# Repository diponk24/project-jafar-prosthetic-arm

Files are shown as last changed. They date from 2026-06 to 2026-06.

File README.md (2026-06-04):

# Project Jafar – Prosthetic Arm

## Overview

Project Jafar is a prosthetic arm prototype designed to explore assistive robotics through EMG-based muscle signal control and voice-command operation.

The arm incorporates a differential mechanism for finger movement, a foldable elbow joint, and rotational elbow motion to replicate essential arm functionalities.

---

## Features

- EMG sensor-based control
- Voice-command operation
- Differential finger actuation mechanism
- Finger folding functionality
- Foldable elbow joint
- Rotatable elbow movement
- Modular design for future upgrades

---

## Working

The prosthetic arm can be controlled using:

1. **EMG Sensors**
   - Detect muscle activity from the user.
   - Convert signals into movement commands.

2. **Voice Commands**
   - Execute predefined actions through voice input.

The system performs:
- Finger folding
- Gripping actions
- Elbow folding
- Elbow rotation

---

## Components Used

- Arduino / ESP32
- EMG Sensors
- Servo Motors
- Voice Recognition Module
- Mechanical Differential Mechanism
- Power Supply

---

## Technologies

- Embedded Systems
- Robotics
- Sensor Integration
- Mechanical Design

---

## Future Scope

- Individual finger control
- Improved grip strength
- Wireless connectivity
- Mobile application integration
- Advanced gesture recognition

---

## Team

Project Jafar was developed by a team of 7 members as an assistive robotics and prosthetic arm prototype focused on affordable and practical functionality.

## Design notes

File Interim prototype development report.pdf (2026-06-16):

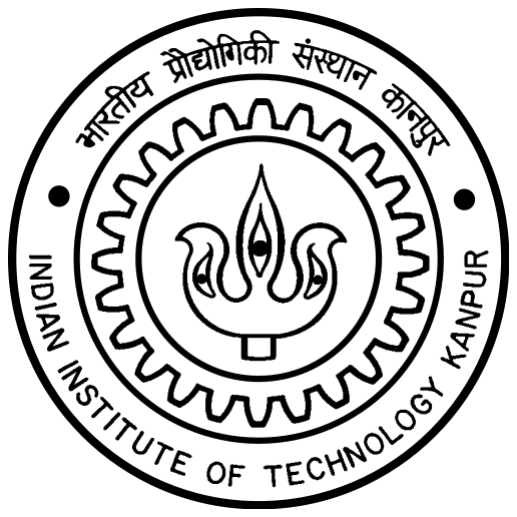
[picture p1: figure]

### Indian Institute of Technology Kanpur

## Department of Mechanical Engineering

# Project Jafar

# Design and Development of a 3D-Printed Differential-Actuated Prosthetic Arm

# Course: ME252 — Theory of Mechanisms and Machines

### Project Team

Anandan Iyer | anandani24@iitk.ac.in | Prakhar | prakhark24@iitk.ac.in
Ayush Dwivedi | ayushd24@iitk.ac.in | Sarthak Patel | sarthakp24@iitk.ac.in
Dipon Konar | diponk24@iitk.ac.in | Shubham | shubham24@iitk.ac.in
Lakshya Gupta | lakshyag24@iitk.ac.in

## June 16, 2026

# Contents

1 Overview | 1
2 Iteration 1: Proof-of-Concept Prototype | 1
3 Iteration 2: Differential-Actuated Multi-DOF System | 1
4 Results and Conclusion | 4
5 Future Scope | 4
References | 5
A Appendix | 5

# 1 Overview

Project Jafar is a noble effort to design and develop a prosthetic arm within an affordable price range for an 8 year old kid named Jafar who doesn’t have the ability to use either of his arms. The first iteration involved fabricating a singe-DOF proof-of-concept which incorporated finger-actuation and the ability to grip fragile objects. In the second iteration, we worked on developing athree-DOF platform incorporating finger actuation and, elbow flexo-extension driven by a differential actuation mechanism and controlled wirelessly via an ESP32 microprocessor.

Parameter | Iteration 1 | Iteration 2
DOF | 1 (Finger actuation) | 3 (Finger, Elbow, Prono)
Actuation | Direct string, single motor | Differential mechanism
Microcontroller | Arduino Nano | ESP32
Input modality | EMG sensor | Bluetooth & Wi-Fi voice
Tendon routing | Ad-hoc, unguided | Guided channels + hooks
Table 1: High-level comparison across design iterations.

# 2 Iteration 1: Proof-of-Concept Prototype

## 2.1 Mechanical Design

Iteration 1 employed asingle motor which drives fingers simultaneously through a combined string tendon arrangement: individual finger strings were merged upstream and connected to a single motor. Although the mechanism was quick to implement, it was prone to multiple failures.
- No force distribution: equal motor tension was applied uniformly to all tendons regardless of per-finger contact resistance or object interaction which resulted in disproportionate actuation and instability.
- Inconsistent string tension: unguided routing introduced variable friction, slack, and path-dependent losses, which lead to unpredictable grip profiles.
- Recurring string failures: uncontrolled routing concentrated stress at sharp bends, contact edges, and termination points, accelerating wear and leading to frequent tendon breakage under cyclic loading.
- Rigid inter-finger coupling: all fingers were mechanically linked which prevented them from moving independently that highlighted another design flaw. The elbow joint was kept passive for this prototype, which housed the 7.4V battery, which was used to drive the motor.

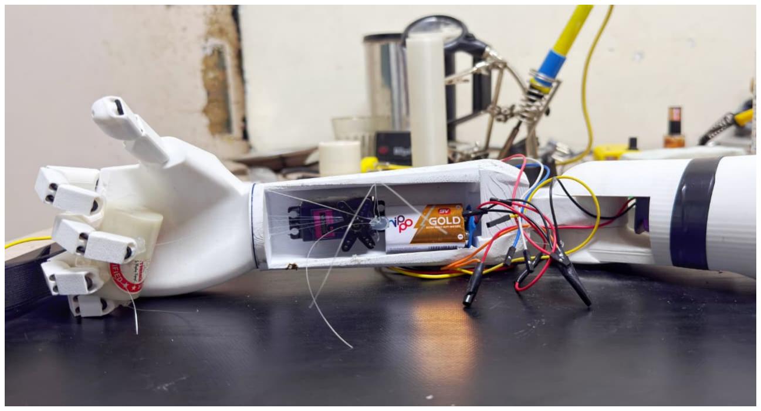
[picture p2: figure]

Figure 1: Iteration I prototype: signle-DOF combined-string finger actuation

## 2.2 Control System

The control architecture used an Arduino Nano to sample the analogue voltage from a surface EMG sensor band. Myoelectric potentials were kept as threshold to generate binary motor on/off commands. Reliable electrode placement was another hurdle; we were seldom able to position EMG bands correctly, which led to difficulties in interpreting the signal. Attempts were made to set the motor’s position based on the signal strength received, but the attempts failed because the signal was not stable enough, this led to the limitation to keep fingers either fully open or closed, and not in any intermediate state.
These issues collectively led to the full architectural redesign leading to Iteration 2.

# 3 Iteration 2: Differential-Actuated Multi-DOF System

## 3.1 Redesign Rationale

The transition to Iteration 2 was driven by a few principal deficiencies, along with a shift in the control strategy from the EMG-based sensing used in the first iteration to a more reliable and implementable approach: (i) Structural inconsistencies in the CAD model with no defined tendon pathways or dedicated electronics accommodation. (ii) Recurring string failures from uncontrolled stress concentrations. (iii) Unreliable finger control from a coupled tendon architecture. (iv) The single-DOF constraint precluding the three-DOF mobility required for functional prosthetic use.

## 3.2 Three-DOF Mechanical Architecture

The upgraded system implements three independently motorised degrees of freedom. DOF 1 provides finger actuation via the differential mechanism (Section 3.3). DOF 2 delivers elbow flexo-extension through a direct-drive scheme in which the motor housing is fixed to the upper-arm segment and the output shaft is rigidly coupled to the forearm, producing pure joint rotation without additional transmission elements. DOF 3 enables forearm pronosupination via a motor whose axis is co-axial with the forearm’s longitudinal centre-line. All three motors are independently addressable through dedicated PWM channels on the ESP32.

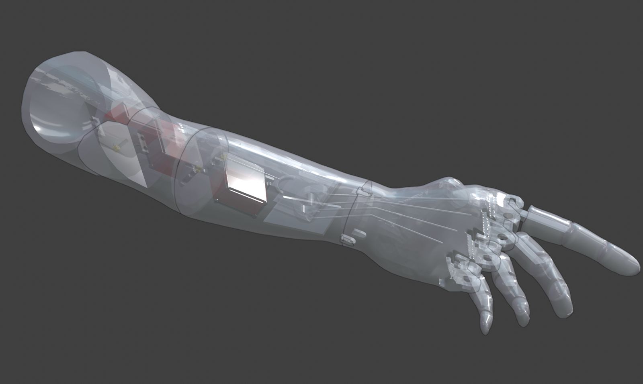
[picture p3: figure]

Figure 2: Iteration 2 three-DOF kinematic layout: motor placement and joint axes.

## 3.3 Differential Finger Actuation

### 3.3.1 Objective

As established in Section 2.1 (Mechanical Design), the initial finger actuation required a more robust system for force distribution, hence we will be implementing a differential mechanism for this part of the prosthetic. The differential mechanism enabled a balanced and adaptive force distribution among the fingers, allowing actuation to adjust based on resistance at each finger. If one of the fingers faces resistance when gripping a particular object, the rest of the the fingers continue to grip around the object, and when all the fingers curl, further tension in the strings start to grip the object tighter. This resulted in a smoother motion and improved grasping performance, especially when contact conditions vary across fingers.

### 3.3.2 Working principle

Based on the kinematic constraints of strings, the displacement of the primary pulley P3 ( is distributed through the differential tree according to the following relations:

D5 + D6 = 2D7

D1 + D2 = 2D5

D3 + D4 = 2D6

When one of the fingers start feeling resistance, say finger 1 for example, it would stop moving, and rest of the motion would go instead to its coupled finger, in this case finger 2 (D1 = 0 and D2 = 2D5). In case both the coupled fingers feel resistance, then the motion would instead go to the other coupled pulley. (In this case for example, P1 stops moving and P2 take all the motion). The physical definition of each variable is illustrated in Figure 3:

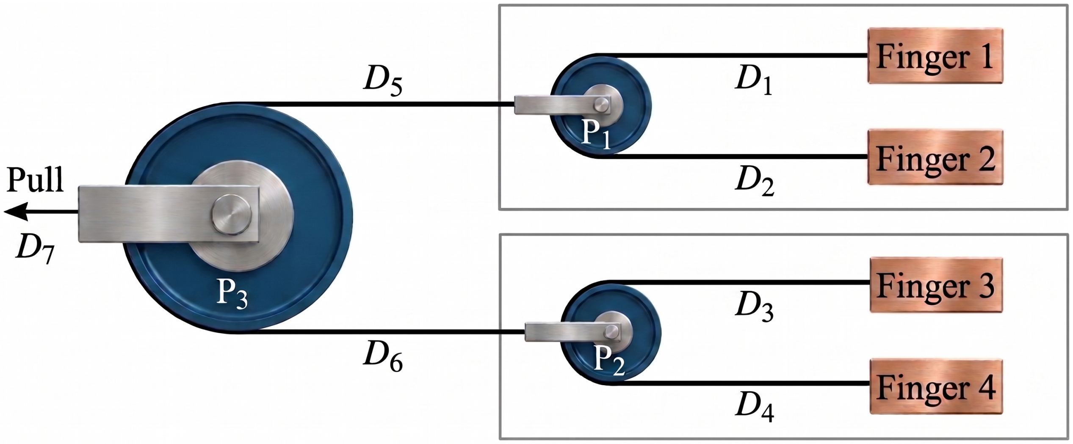
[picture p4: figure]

Figure 3: Simplified view of a differential mechanism

### 3.3.3 Implementation

In our implementation of the differential mechanism, given space constraints, we had to move away from the basic pulley-based Atwood machine shown in Figure 3. Our approach combined the pulleys P1, P2, and P3 into one single mechanism. The heart of the mechanism is shown in blue atop the pink slide, which slides comfortably into the red slot (as seen in Figure 4). In the front part, which opens towards the fingers (which functionally acts like P1 and P2 and are similar to traditional pulleys), there are holes for strings to enter, with a toroidal cavity for each pair of fingers. The string can move freely (after using a suitable lubricant, so the string does not wear out). To implement the P3, the Blue part uses the red part as a hinge to rotate. When there is unequal motion between pulleys P1 and P2, the blue part rotates about the red part; thus, if required and one of the pulleys stalls due to resistance, the mechanism can continue sliding, on the tracks, with the blue part rotating to accomodate the movement.

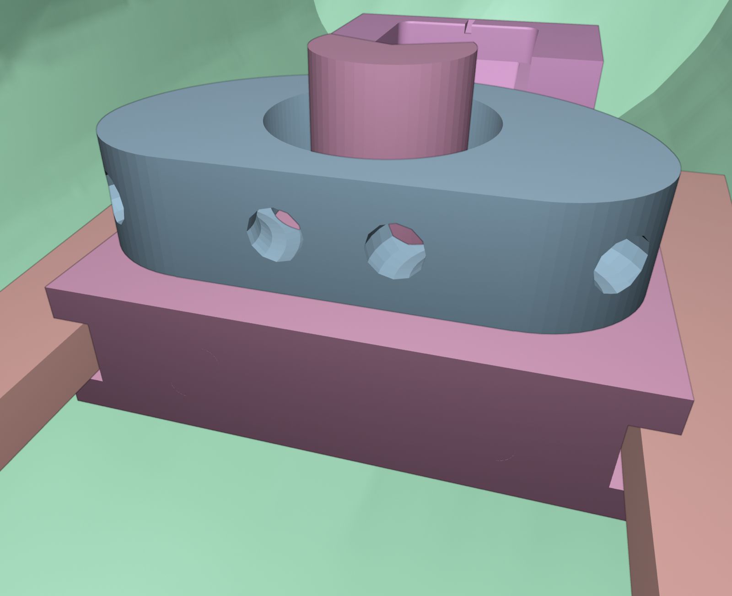
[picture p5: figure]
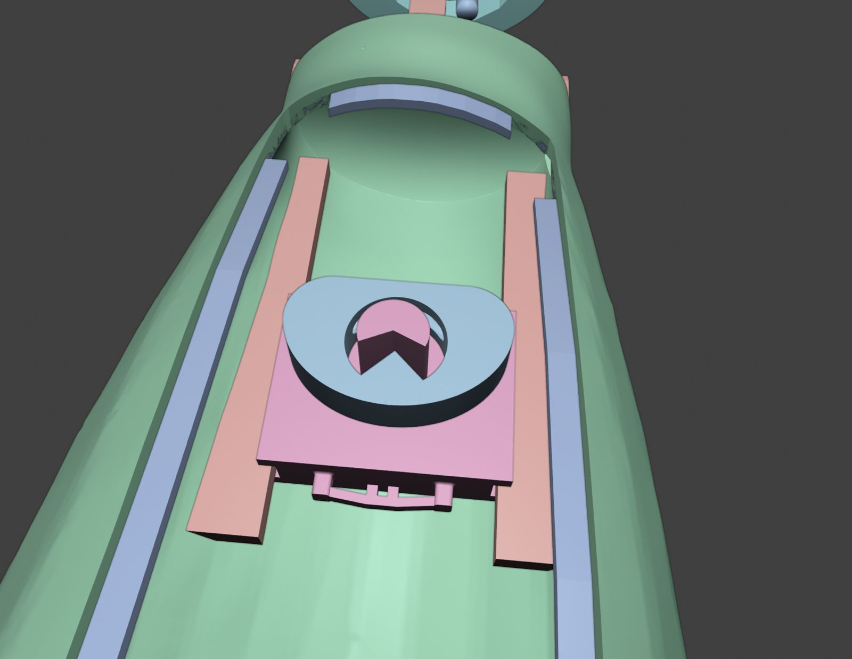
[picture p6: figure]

(a) Bird’s-eye view. | (b) Close-up view.
Figure 4: Views of the differential mechanism assembly.
Property | Iteration 1 - Prototyping | Iteration 2 - Differential
Force distribution | Equal, load-independent | Adaptive per-finger
Grasp adaptability | None (rigid coupling) | Passive compliance
Tendon routing | Unguided, ad-hoc | Guided channels + hooks
Frictional losses | High (uncontrolled contacts) | Reduced (smooth guided paths with lubrication)

Table 2: Actuation mechanism comparison across iterations.

## 3.4 CAD Redesign

The updated design adopts a more structured and integrated approach to improve overall system performance. The forearm geometry was redesigned to enable functioning of both the actuation system and electronics within a dedicated internal cavity which significantly improves the spatial organization, component protection, and the ease of assembly. Carefully planned provisions for servo placement and wire routing have been useful in reducing clutter, minimized interference between components, and enhanced long-term maintainability and serviceability. The forearm was also modified to better integrate the differential mechanism which resulted in more efficient force transmission and smoother, more coordinated motion during operation. In addition, the upper arm was redesigned to incorporate an extra degree of freedom at the elbow joint(passive in the initial iteration), which increases the overall range of motion of the system. Further improvements were made to the palm and finger assemblies. Guided string channels were built directly into the CAD model, replacing the earlier ad-hoc routing approach to ensure a cleaner and more reliable tendon path. Intermediate hooks and supports were added along the tendon path to maintain proper alignment to reduce slack and minimize frictional losses during the motion. These changes ensure a more consistent tension distribution and smoother, more precise actuation across all fingers.

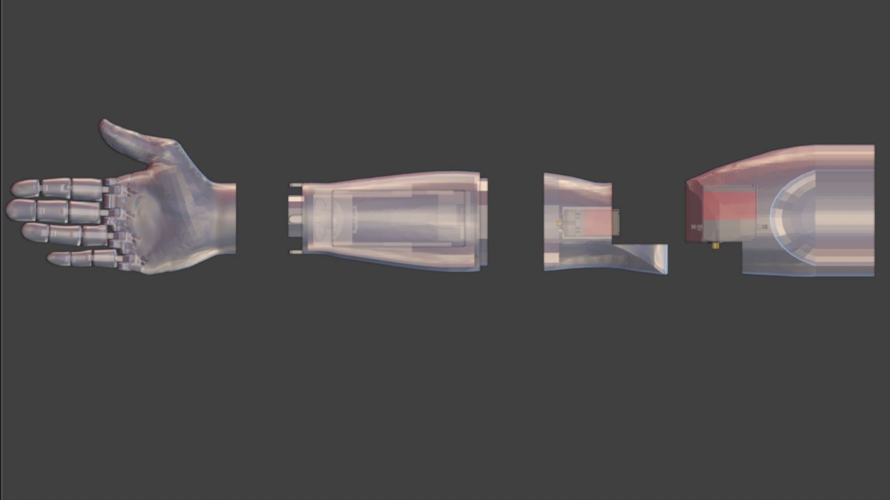
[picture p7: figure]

(a) Iteration 1: unstructured interior

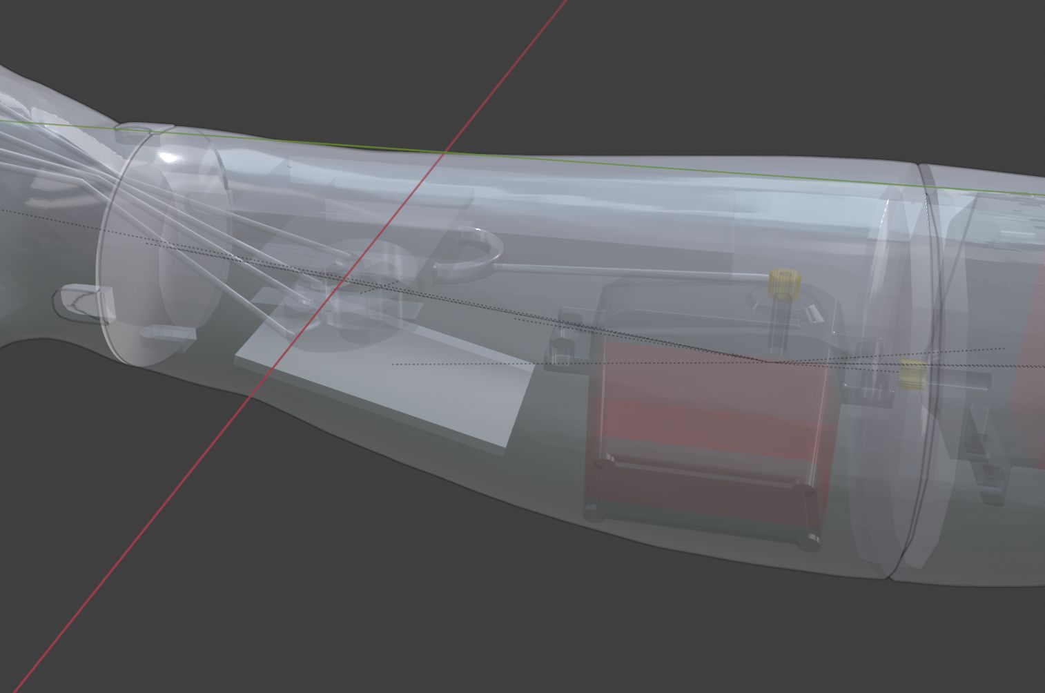
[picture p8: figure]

(b) Iteration 2: CAD with integrated cavity, servo mounts, and wire channels

## 3.5 Electronics and Control System

### 3.5.1 Control Architecture

The control system is built around the ESP32 microcontroller, selected for its integrated Bluetooth and Wi-Fi capabilities. This enables multiple wireless input methodologies on a single hardware platform while providing sufficient PWM-capable GPIO pins for independent control of the finger and elbow actuation motors.
To ensure stable operation, the motor supply and logic supply are regulated independently. This minimizes switching transients generated by the motors, thereby improving system reliability and preventing voltage fluctuations from affecting control performance.

### 3.5.2 Wireless Control Methodologies

During development, we tried out two wireless approaches. This revealed a clear trade-off: one was much simpler to implement, but the other gave the system far more autonomy.

Bluetooth Serial Interface

In the initial approach, the ESP32 was configured as a Bluetooth device and paired with a mobile phone. Commands were transmitted using a Bluetooth Serial Terminal application, with Google Assistant acting as a voice-to-text front-end.
The spoken command was converted to text via cloud-based processing and relayed to the ESP32, where it was parsed against predefined command tokens. While straightforward to implement, this method suffered from internet dependency, increased latency, and reduced reliability under wireless interference.

Wi-Fi Offline Voice Interface

To overcome these limitations, a Wi-Fi-based offline voice interface was implemented. A Python script running on a laptop connected to the ESP32 over a local Wi-Fi network utilizes a pretrained offline speech recognition library (Vosk) to detect predefined command phrases. Recognized commands are transmitted to the ESP32 via HTTP requests, enabling real-time actuation without reliance on internet connectivity. The command structure was designed for clarity and robustness. Finger actuation (DOF 1) is controlled using discrete commands, while higher degrees of freedom corresponding to elbow and rotational motion (DOF 2 and DOF 3) follow a structured format. The actuation angles are limited to fixed values such as 0°, 30°, 60°, and 90° for easier control and can be further increased. This separation simplifies parsing and improves recognition reliability.

Voice Command | DOF Target | Motor Action
grip | DOF 1 (Fingers) | Close fingers via differential actuation
loose | DOF 1 (Fingers) | Open fingers (release motion)
motor N turn θ | DOF 2 / DOF 3 | ◦ Rotate motor N to θ
Table 3: Voice command vocabulary and corresponding motor actions.

The Wi-Fi-based interface provides a more reliable and low-latency control solution compared to the Bluetooth approach, making it better suited

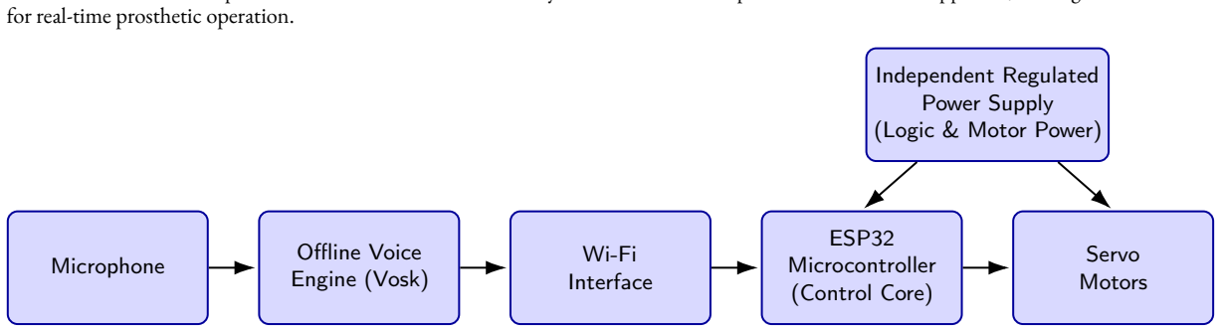
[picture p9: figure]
for real-time prosthetic operation.; Microphone; Offline Voice; Engine (Vosk); Wi-Fi Interface; ESP32 Microcontroller (Control Core); Servo Motors; Independent Regulated Power Supply (Logic & Motor Power)

Figure 5: System control architecture and offline voice communication flow.

# 4 Results and Conclusion

The project progressed through two iterations, each improving upon the limitations of the previous design.
Iteration 1 resulted in a fabricated and tested, successfully demonstrating basic finger actuation. However, issues such as inconsistent tension and unreliable control highlighted the need for redesign.
In Iteration 2, we focused on improving different parts of the system separately. The updated CAD design made the structure more organized and helped in proper routing of the strings. The differential mechanism showed better force distribution and smoother finger movement during testing. On the electronics side, the ESP32 control system and the Wi-Fi based voice interface were tested independently and worked reliably with low delay.
At this stage, all the major subsystems have been developed and tested individually. The next step is to integrate everything together and test the full system with all degrees of freedom working simultaneously. Overall, the second iteration provides a much more stable and improved base compared to the first prototype.

# 5 Future Scope

The next step is to integrate all the subsystems and test the complete prosthetic arm. This includes running all three degrees of freedom together and checking performance during actual grasping tasks. The control system can be improved by bringing back EMG-based input or using physical buttons along with voice commands for more intuitive use. Adding feedback systems, such as force or position sensing, can help improve accuracy and control. On the mechanical side, further refinement of the differential mechanism and string routing can reduce friction and improve durability. Reducing weight and making the design more compact will also improve usability. The command input can be expanded to allow smoother and more precise movements instead of only fixed angle steps. Overall, the current design provides a good base for developing a more reliable and user-friendly prosthetic arm.

# References

V. Khatik and A. Saxena, “A Novel Slack Tolerant, Sliding Pulley Differential Mechanism for Adaptive Grasping,” Proc. ASME IDETC-CIE, 47th Mechanisms and Robotics Conf., Vol. 8, p. V008T08A071, Aug. 2023. doi: 10.1115/DETC2023-115115.

Viral Science Creativity, “Arduino Flex Sensor Controlled Robot Hand,” Sep. 18, 2022. Available: https://www.viralsciencecreativity.com/post
/arduino-flex-sensor-controlled-robot-hand.

Enabling the Future, “Upper Limb Prosthetics,” Available: https://enablingthefuture.org/upper-limb-prosthetics/

Kwawu Arm Project, “Kwawu Arm 3.0 Wrap Version,” Available: https://www.printables.com/model/653545-kwawu-arm-30-wrap-version

# A Appendix

## A.1 Python Voice Recognition Script

import sounddevice as sd
import json
from vosk import Model , KaldiRecognizer import requests

model = Model (" model ")

rec = KaldiRecognizer (
model , 16000 ,
’[" grip " ," loose " ," motor one " ," motor two " ," turn " ," zero " ," thirty " ," sixty " ," ninety "] ’

)

ESP_IP = " 192.168.4.1 "

motor_map = {
"one ": 1 ,
"two ": 2

}

angle_map = {
" zero ": 0,
" thirty ": 30 ,
" sixty ": 60 ,
" ninety ": 90

}

def send ( cmd , motor = None , angle = None ) : try :
if cmd in [" grip ", " loose "]:
url = f" http ://{ ESP_IP }/ cmd ? mode ={ cmd }"
else :
url = f" http ://{ ESP_IP }/ cmd ? mode = move & motor ={ motor }& angle ={ angle }"

requests . get ( url )
print (" Sent :", url )

except :
print (" ESP not connected ")

def process ( text ):
print (" Heard :", text )

if " grip " in text :
send (" grip ")
return

if " loose " in text :
send (" loose ")
return

motor = None

53 | angle = None

54
55 | for word in motor_map :
56 | if word in text :
57 | motor = motor_map [ word ]

58
59 | for key in angle_map :
60 | if key in text :
61 | angle = angle_map [ key ]

62
63 | if motor and angle is not None :
64 | send (" move ", motor , angle )

65
66 | def callback ( indata , frames , time , status ):
67 | if rec . AcceptWaveform ( bytes ( indata )) :
68 | result = json . loads ( rec . Result () )
69 | text = result . get (" text ", "")

70
71 | if text :
72 | process ( text )

73
74 print (" Speak now ... ")

75
76 | with sd . RawInputStream ( samplerate =16000 ,
77 | blocksize =8000 ,
78 | dtype =’int16 ’,
79 | channels =1 ,
80 | callback = callback ) :
81 | while True :
82 | pass

## A.2 ESP32 Control Code

1
2 | # include < WiFi .h >
3 | # include < WebServer .h >
4 | # include < ESP32Servo .h >

5
6 WebServer server (80) ;

7
8 | Servo finger ; | // DOF 1
9 | Servo elbow1 ; | // DOF 2
10 | Servo elbow2 ; | // DOF 3

11
12 | void handleCmd () {
13 | String mode = server . arg (" mode ");

14
15 | if ( mode == " grip ") {
16 | finger . write (90) ; | // close
17 | }

18
19 | else if ( mode == " loose ") {
20 | finger . write (0) ; | // open
21 | }

22
23 | else if ( mode == " move ") {
24 | int motor = server . arg (" motor "). toInt () ;
25 | int angle = server . arg (" angle ") . toInt () ;

26
27 | if ( motor == 1) elbow1 . write ( angle ) ;
28 | if ( motor == 2) elbow2 . write ( angle ) ;
29 | }

30
31 | server . send (200 , " text / plain ", "OK");
32 | }

33
34 void setup () {

35 | WiFi . softAP (" ESP32_ARM ", " 12345678 ");

36
37 | finger . attach (13) ;
38 | elbow1 . attach (12) ;
39 | elbow2 . attach (14) ;

40
41 | server . on ("/cmd ", handleCmd );
42 | server . begin () ;
43 | }

44
45 | void loop () {
46 | server . handleClient () ;
47 | }

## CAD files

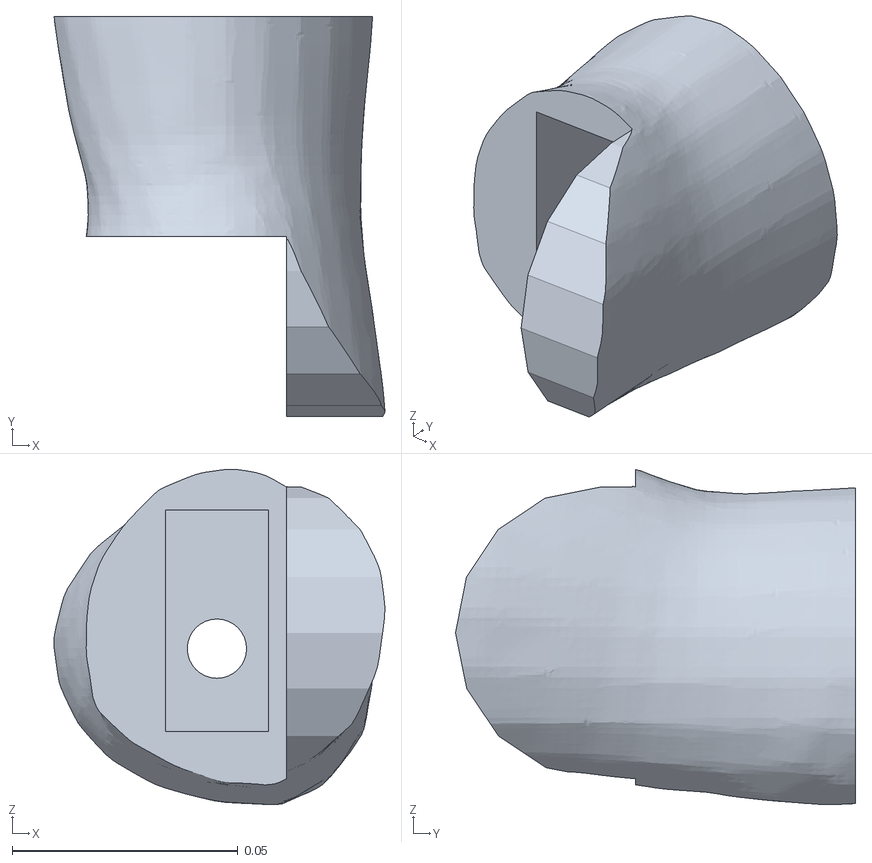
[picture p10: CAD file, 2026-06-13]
JAFAR CAD post modification/Fingers/Arm/elbow.stl
0.0733 x 0.0886 x 0.0743

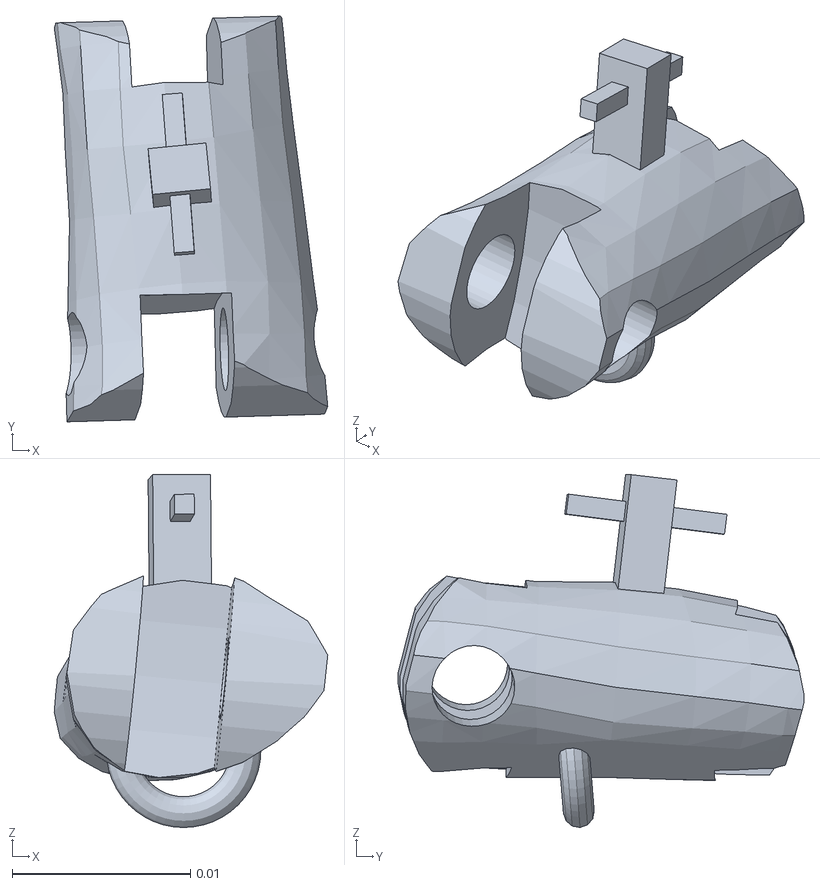
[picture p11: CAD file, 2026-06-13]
JAFAR CAD post modification/Fingers/m_m stl.stl
0.0153 x 0.0227 x 0.0198

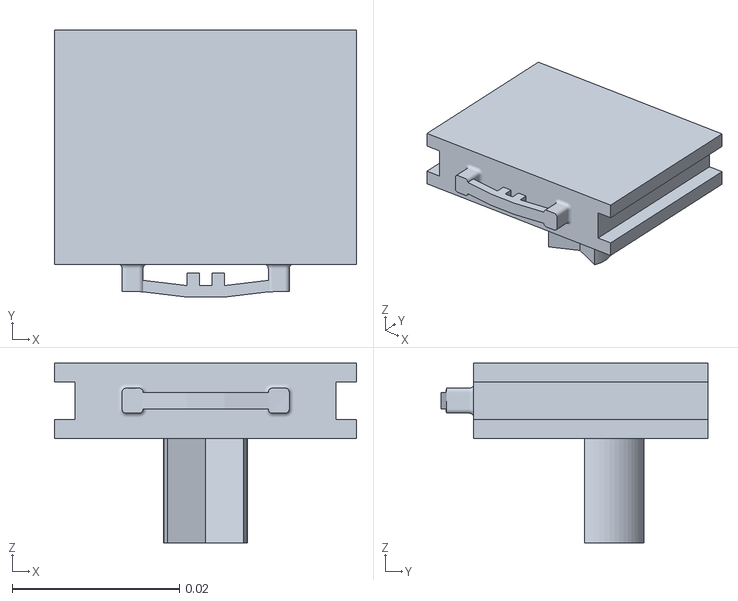
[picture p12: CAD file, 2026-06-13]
JAFAR CAD pre-modified/ARM/DIFFERENTIAL/Base.stl
0.0361 x 0.0319 x 0.0215

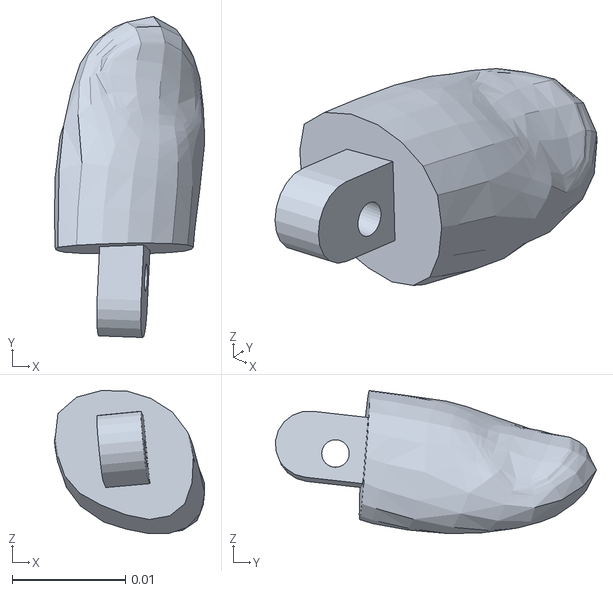
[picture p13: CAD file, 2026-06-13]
JAFAR CAD pre-modified/ARM/DIFFERENTIAL/PALM/INDEX/3.stl
0.0132 x 0.0283 x 0.0126

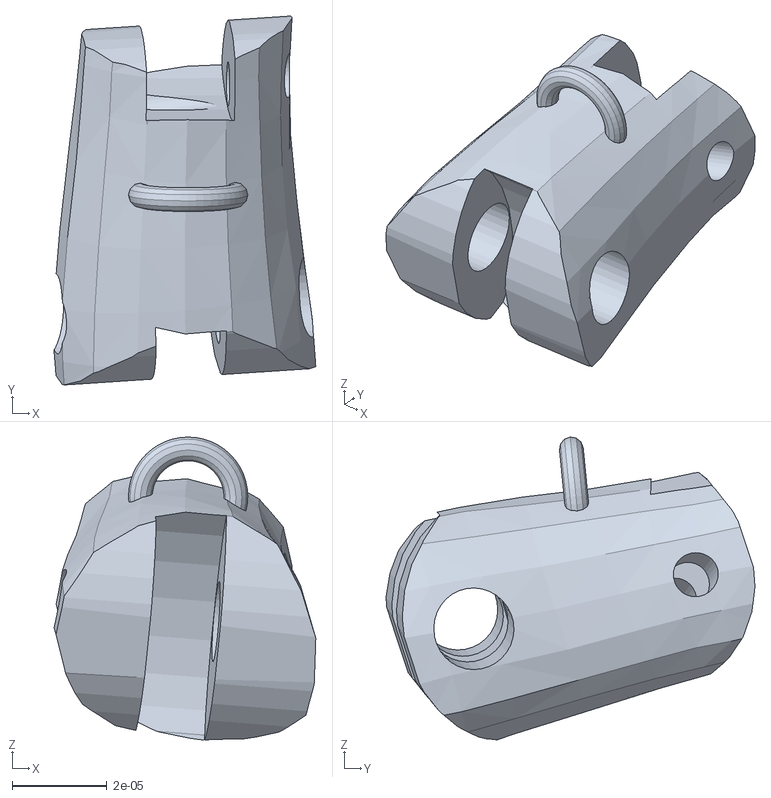
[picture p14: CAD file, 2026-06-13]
JAFAR CAD pre-modified/ARM/DIFFERENTIAL/PALM/LITTLE/2.stl
5.53e-05 x 7.81e-05 x 6.41e-05

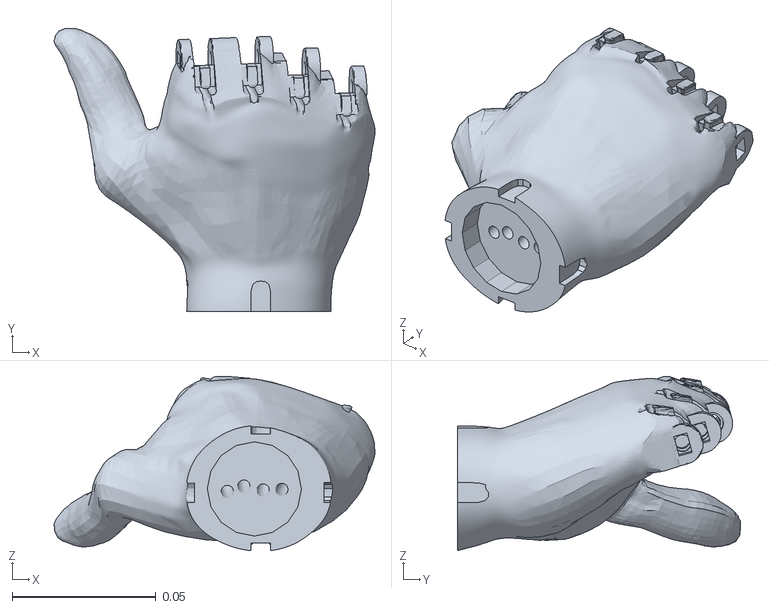
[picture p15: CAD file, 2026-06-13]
JAFAR CAD pre-modified/ARM/DIFFERENTIAL/PALM/MAIN/PALM.stl
0.112 x 0.0985 x 0.0606

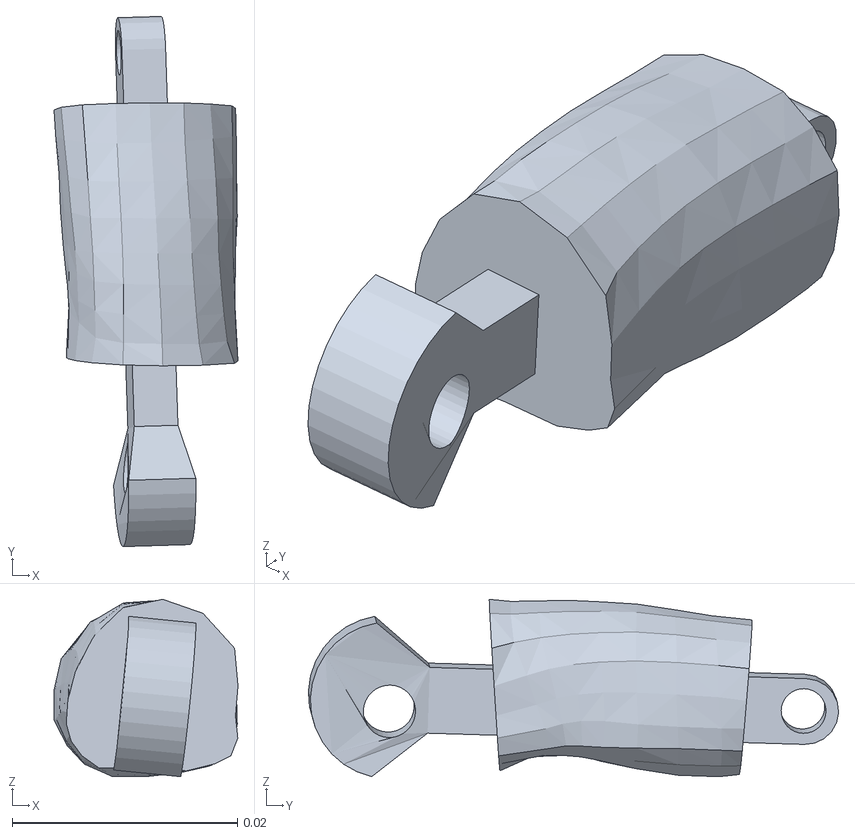
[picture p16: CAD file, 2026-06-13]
JAFAR CAD pre-modified/ARM/DIFFERENTIAL/PALM/MID/1.stl
0.0163 x 0.0471 x 0.0157

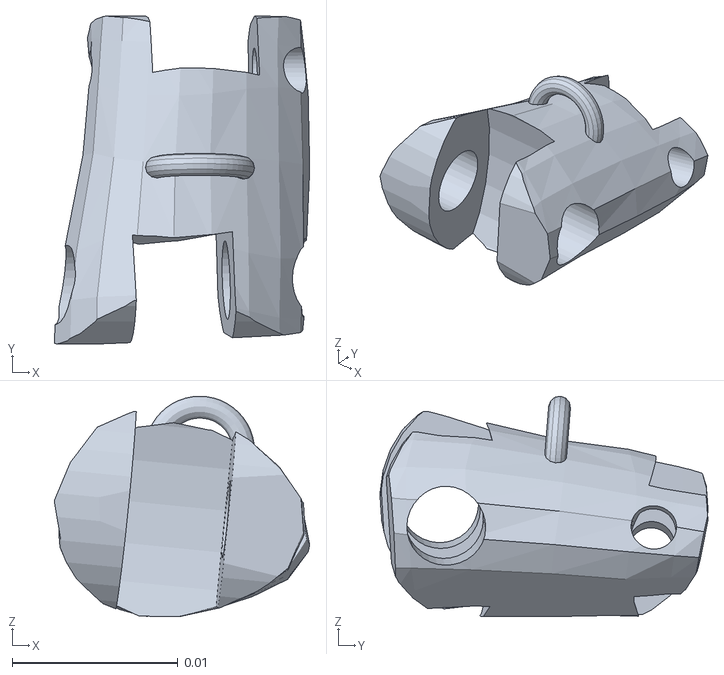
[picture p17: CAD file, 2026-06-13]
JAFAR CAD pre-modified/ARM/DIFFERENTIAL/PALM/RING/2.stl
0.0154 x 0.0198 x 0.0133

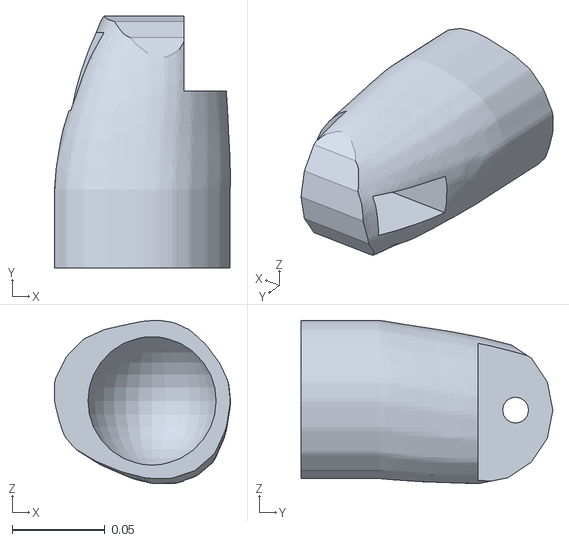
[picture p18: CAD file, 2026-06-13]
JAFAR CAD post modification/Fingers/Arm/bicep.stl
0.0946 x 0.135 x 0.0878

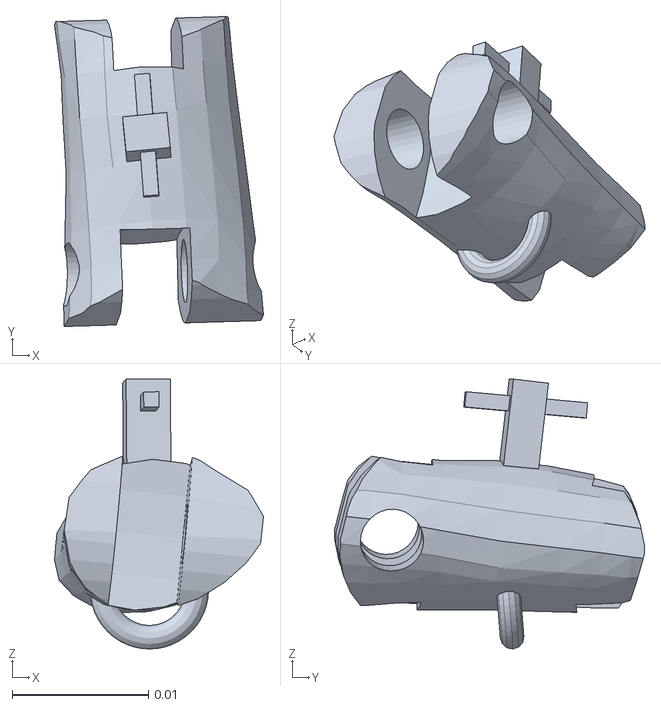
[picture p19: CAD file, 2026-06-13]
JAFAR CAD post modification/Fingers/i_m stl.stl
0.0153 x 0.0227 x 0.0198

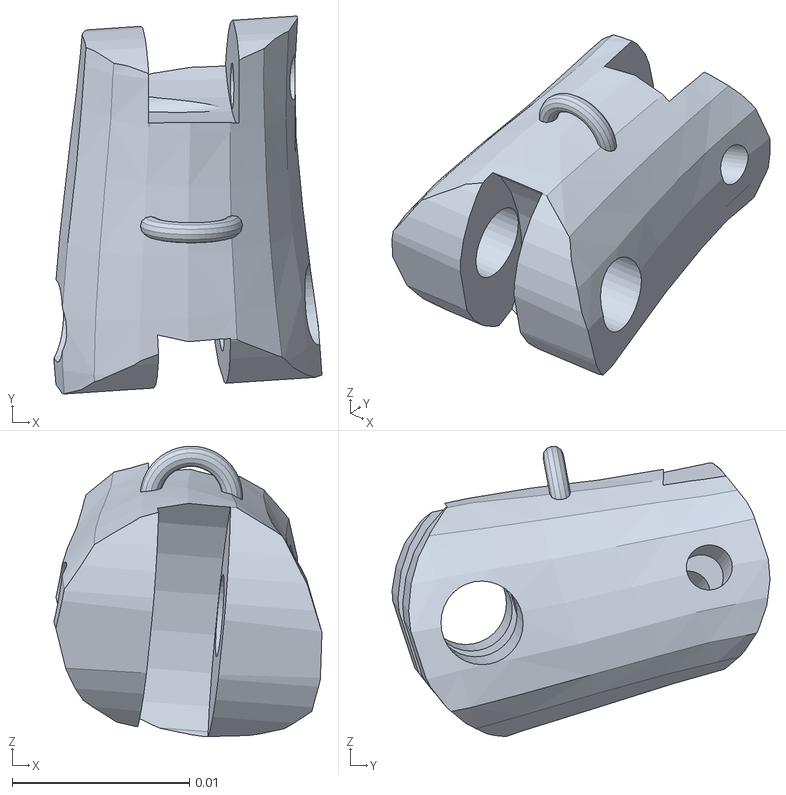
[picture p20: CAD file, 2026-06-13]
JAFAR CAD pre-modified/ARM/DIFFERENTIAL/PALM/INDEX/2.stl
0.0151 x 0.0213 x 0.0164

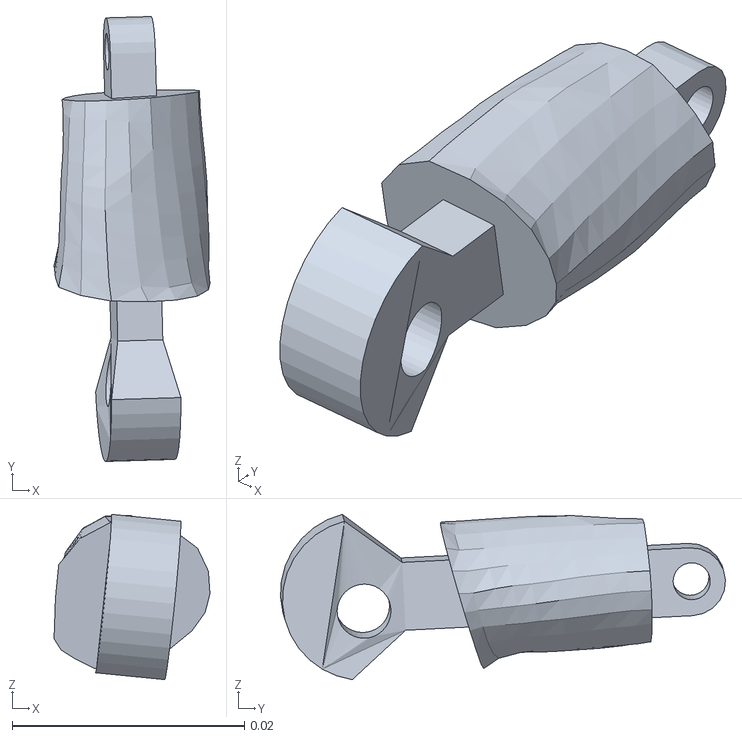
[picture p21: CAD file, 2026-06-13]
JAFAR CAD pre-modified/ARM/DIFFERENTIAL/PALM/LITTLE/1.stl
0.0134 x 0.0383 x 0.0142

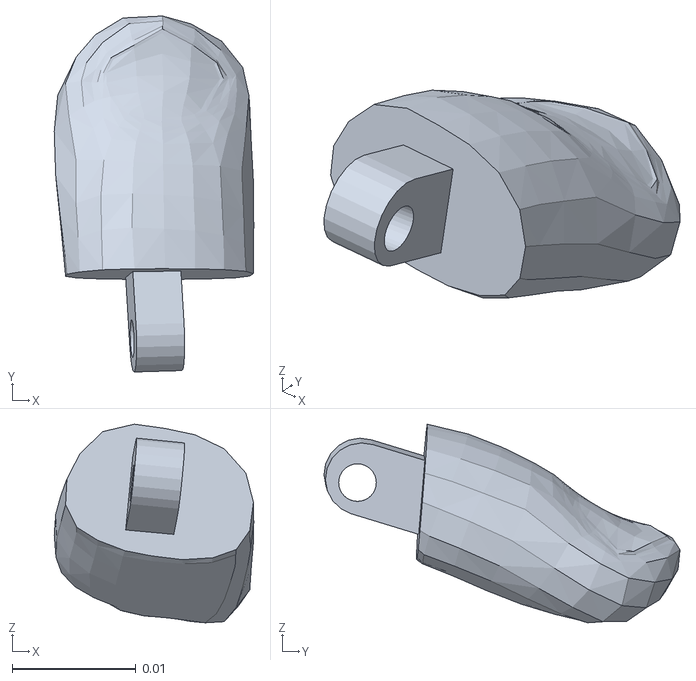
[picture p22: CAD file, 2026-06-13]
JAFAR CAD pre-modified/ARM/DIFFERENTIAL/PALM/MID/3.stl
0.0161 x 0.0287 x 0.016

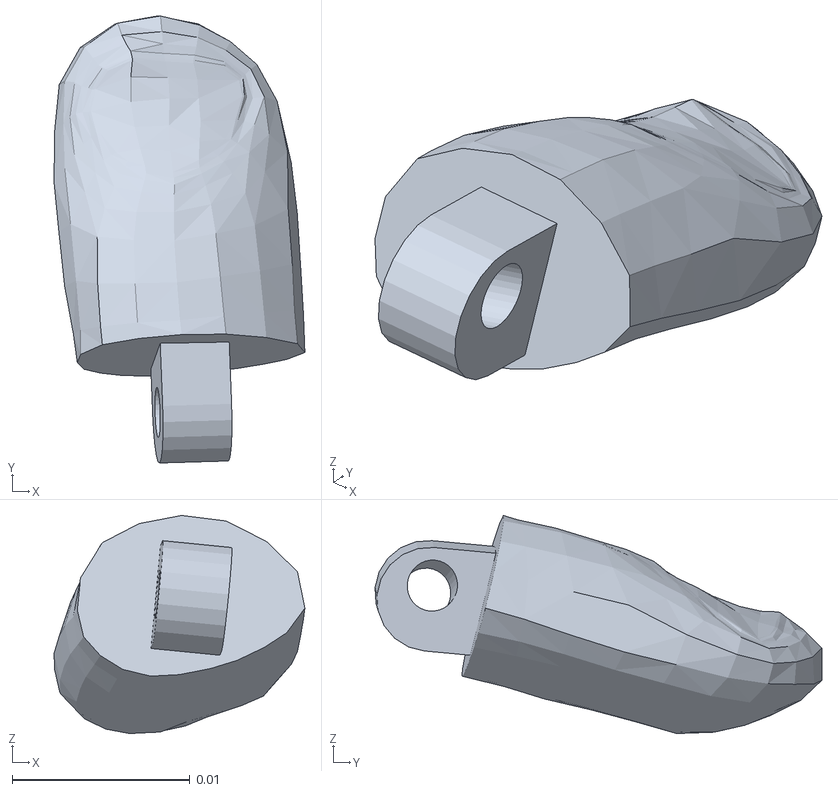
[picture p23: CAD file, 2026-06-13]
JAFAR CAD pre-modified/ARM/DIFFERENTIAL/PALM/RING/3.stl
0.0141 x 0.0251 x 0.0123

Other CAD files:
JAFAR CAD pre-modified/ARM/DIFFERENTIAL/TOP.stl
JAFAR CAD post modification/Fingers/Arm/base.stl
JAFAR CAD post modification/Fingers/little_m.stl
JAFAR CAD pre-modified/ARM/DIFFERENTIAL/PALM/INDEX/1.stl
JAFAR CAD post modification/Fingers/Arm/cylinder.stl
JAFAR CAD post modification/Fingers/i_d stl.stl
JAFAR CAD post modification/Fingers/index lowee.stl
JAFAR CAD post modification/Fingers/l_d stl.stl
JAFAR CAD post modification/Fingers/l_m stl.stl
JAFAR CAD post modification/Fingers/little.stl
JAFAR CAD post modification/Fingers/little_d.stl
JAFAR CAD post modification/Fingers/m_d stl.stl
JAFAR CAD post modification/Fingers/m_d.stl
JAFAR CAD post modification/Fingers/mid lower.stl
JAFAR CAD post modification/Fingers/mid upper.stl
JAFAR CAD post modification/Fingers/r_d stl.stl
JAFAR CAD post modification/Fingers/r_m stl.stl
JAFAR CAD pre-modified/ARM/DIFFERENTIAL/PALM/LITTLE/3.stl
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
